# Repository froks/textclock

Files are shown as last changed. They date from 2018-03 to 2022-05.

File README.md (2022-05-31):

textclock
=========

# Introduction

textclock is a parametric 3d-printable textclock. It's currently in development.

It's designed to be used with a 60 led/m SK6812 led-strip, and an esp8266 using micropython for control. 
Using an ESP32 or any other micropython-capable board is also possible, but timer handling and pins might 
need to be changed.

The letterface is available in English and German, but can be easily adapted to other languages, as well as your
specific needs. The letters "stamped" into clock are just configuration files with text - look at the 
[english one](hardware/config_sk6812_english_minimal.scad) for a glimpse.

The configuration for most parameters is also adjustable in the [config_common.scad](hardware/config_common.scad) file. 

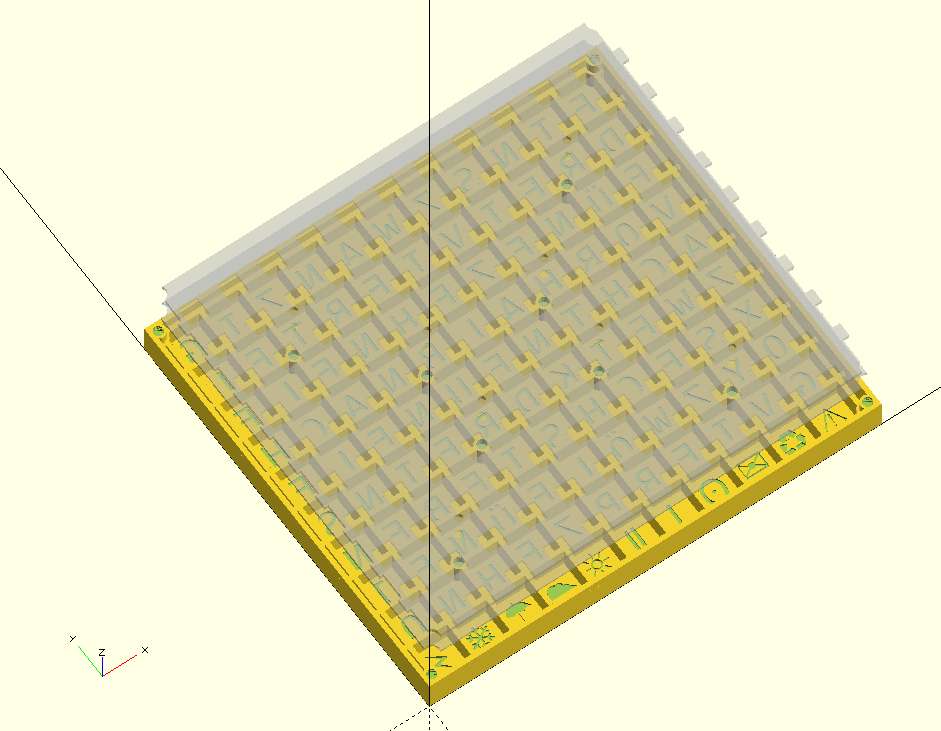
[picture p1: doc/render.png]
rendering


# Requirements

## Parts / BOM

In the default configuration the clock requires the following parts:

### 3d printed parts

__Note: Please read the Printed parts (IMPORTANT!)" section before you print them__

- letter plate (front face of the clock, includes the letters shown and separation between them)
- led holder plate (used with fixation plate to clamp the led strips between them)
- led fixation plate (used to clamp strips & serves as mount for electronics)
- backplate/wallmount (to close the case and enable mounting it to a wall)

### hardware
- M2.5 brass threaded inserts
- M2.5 machine screws (short, maybe 6mm?)

### electronics
- ESP8266 (or ESP32) NodeMCU-style board 
- SK6812 60 LEDs/m RGBW strip
- DS1307 RTC module (I used a dual module called "Tiny RTC" that additionally includes an eeprom, and just didn't it)
- THT angled pin headers (2.54mm)
- Jumper wires (F-F, just cut them up)
- misc. cables (you can use the jumper wire remains)

Since the 3d files are written in OpenSCAD, you can modify them to your needs and available electronics or led strips.  

## Printed parts (IMPORTANT!)

- 0.15mm layer height (some parameters in `config_common.scad` need to be changed if you want to use a different height)
- 0.4mm nozzle (for more detailed letters, you could potentially use a smaller nozzle)
- Filament: __Your filament choice is crucial for success.__ It must be opaque enough to block the light at ~1mm height, 
  but let light through at 0.15mm (single layer height). You can print a smaller test print
  to determine if your filament is suitable.   

# Assembly

## Printed parts

### Install threaded inserts

### Install led strips

## Electronics

### Prepare ESP8266

First step is to solder the angled pin headers to the ESP8266 board. Please note, that you may need to remove the 
standard headers first. 

## Software

The process of installing the software is described in the [software-folders README](software/README.md)

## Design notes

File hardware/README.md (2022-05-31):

### Recreate required stls

To recreate the required STL-files, you can run `build.bat`. Please note, that OpensCAD needs to be installed in `%PROGRAMFILES%\OpenSCAD\openscad.exe`.

If you want to manually recreate the files, you need to open, render & export the following files in OpenSCAD:
- led_fixation_plate.scad
- led_holder_plate.scad
- backplate_wall.scad
- letter_plate.scad

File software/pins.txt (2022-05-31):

ESP8266:

In most cases only pins 0, 2, 4, 5, 12, 13, 14, 15, and 16 can be used.

On my board:
Pin(0) = D3
Pin(2) = switches LED near antenna (low = led on)
Pin(4) = D2
Pin(5) = D1
Pin(12) = D6

sda = D2 = 4
scl = D1 = 5

import machine

i2c = machine.I2C(freq=100000,scl=machine.Pin(5), sda=machine.Pin(4))

import urtc

rtc = urtc.DS1307(i2c, 104)

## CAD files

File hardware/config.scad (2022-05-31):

include <config_common.scad>
include <config_sk6812_english_minimal.scad>
//include <config_sk6812_german.scad>
//include <config_tester.scad>
include <constants_calculated.scad>

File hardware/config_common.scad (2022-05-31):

$fn=20;

// Distance between two leds on a strip - depending on your mounting direction, only one is actually relevant,
// but to keep the clock square, they should be the
LED_STRIPE_HORIZ_DISTANCE = 16.66;
LED_STRIPE_VERT_DISTANCE = 16.66;

// The size of a single led module on that strip

// The stripe-segments are soldered together, at those points the distance between leds varies a lot,
// sometimes resoldering is required, so the distances between the leds match up
LED_STRIPE_LED_WIDTH = 8;
LED_STRIPE_LED_HEIGHT = 8;

// Since there are small capacitors right next to the leds, we need to provide a little space for them
LED_STRIPE_CAP_WIDTH = 3;
LED_STRIPE_CAP_HEIGHT = 5;
LED_STRIPE_CAP_DEPTH = 1.5; // 1;

// Defines the offset for those capacitors from the leds
LED_STRIPE_CAP_OFFSET_X = -4;
LED_STRIPE_CAP_OFFSET_Y = 0;

// Parameters for the screw holes
LETTER_PLATE_SCREW_INSERT_HEIGHT = 6; // 3.5;
LETTER_PLATE_SCREW_INSERT_WALL_THICKNESS = 2;
LETTER_PLATE_SCREW_INSERT_DIAMETER = 4; // M3 threaded insert diameter
LETTER_PLATE_SCREW_WALL_DIAMETER = LETTER_PLATE_SCREW_INSERT_DIAMETER + LETTER_PLATE_SCREW_INSERT_WALL_THICKNESS;
SCREW_DIAMETER = 3.2; // M3 screw diameter with tolerance

// Parameters for the corner holes (used to mount wallplate)
CORNER_MOUNTING_HOLE_INSERT_HEIGHT = LETTER_PLATE_SCREW_INSERT_HEIGHT;
CORNER_MOUNTING_HOLE_INSERT_DIAMETER = LETTER_PLATE_SCREW_INSERT_DIAMETER;
CORNER_MOUNTING_HOLE_INSERT_WALL_THICKNESS = LETTER_PLATE_SCREW_INSERT_WALL_THICKNESS;
CORNER_MOUNTING_HOLE_WALL_DIAMETER = CORNER_MOUNTING_HOLE_INSERT_DIAMETER + CORNER_MOUNTING_HOLE_INSERT_WALL_THICKNESS + 1;
CORNER_MOUNTING_HOLE_OFFSET = 1.85;

OUTER_HOLES_DIST = 2;
INNER_HOLES_DIST = 4;

LETTER_PLATE_LETTER_BOTTOM = 0.15;
LETTER_PLATE_THICKNESS = 1.05;
LETTER_SEPARATOR_THICKNESS = 2;
LETTER_SEPARATOR_HEIGHT = 10;

LED_HOLDER_PLATE_HEIGHT = 1.5;
INNER_PLATE_TOLERANCE = 1;

LED_HOLDER_PLATE_DIVIDER_CUTOUT_DEPTH = 0.6;
LED_HOLDER_PLATE_DIVIDER_CUTOUT_TOLERANCE = 1;

LED_FIXATION_CUTOUT_HEIGHT = 11;
LED_FIXATION_CUTOUT_WIDTH = 6;
LED_FIXATION_PLATE_THICKNESS = 2;

// Height of the backplate
WALLMOUNT_PLATE_THICKNESS = 6;

ELECTRONICS_HEIGHT = 15;

OUTER_WALL_THICKNESS = 2;
OUTER_WALL_HEIGHT = 2 + LETTER_SEPARATOR_HEIGHT +
    (LED_HOLDER_PLATE_HEIGHT-LED_HOLDER_PLATE_DIVIDER_CUTOUT_DEPTH) +
    LED_FIXATION_PLATE_THICKNESS + ELECTRONICS_HEIGHT;
// 2mm height tolerance to adjust fitting and led-stripe height

ROUND_EDGES_RADIUS = 3;

CONFIG_HORIZ_EXTRA = 0;
CONFIG_VERT_EXTRA = 0;


TESTER_MODE = false;

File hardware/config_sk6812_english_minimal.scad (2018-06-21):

// This work is licensed under a Creative Commons Attribution-NonCommercial-ShareAlike 4.0 International License.
// https://creativecommons.org/licenses/by-nc-sa/4.0/
// (c) 2018 Florian Roks <florian.roks (a) gmail.com>

FONT_NAMES = ["DejaVu Sans Mono", // 0
              "DejaVu Sans", // 1
              "Segoe UI Emoji",
			  "Segoe UI Symbol"];     // 2

FONT_SIZES = [10,
              10,
			  9,
			  10];


// FIVE TEN QUARTER TWENTY TWENTYFIVE HALF

// PAST TO 

// ONE TWO THREE FOUR FIVE SIX SEVEN EIGHT NINE TEN ELEVEN TWELVE

// O CLOCK


LETTERFACE = ["TWENTYFIVEN", 
              "QUARTERHALF",
              "TENEPASTNTO",
              "TWONETHREEQ",
			  "SIXFIVEFOUR",
			  "SEVENELEVEN",
			  "NINEIGHTENT",
			  "TWELVE\u263C\u2601\uE288\u2744\u26A1",
			  "\u2022\u2022O'CLOCK\u2022\u2022"];

LETTERFACE_FONTS = ["00000000000",
                    "00000000000",
                    "00000000000",
                    "00000000000",
                    "00000000000",
                    "00000000000",
                    "00000000000",
                    "00000013311",
                    "00000000000"];

CONFIG_HORIZ_EXTRA = 0;
CONFIG_VERT_EXTRA = 0;

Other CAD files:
hardware/config_sk6812_german.scad
hardware/backplate_wall.scad
hardware/common.scad
hardware/config_tester.scad
hardware/constants_calculated.scad
hardware/led_fixation_plate.scad
hardware/led_holder_plate.scad
hardware/letter_plate.scad
hardware/textclock.scad

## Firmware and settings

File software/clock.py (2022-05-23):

import time_funcs
import dst
import utime
import ntptime
import hw
import urtc
from config import LOCALE_SPECIFIC_PIXEL_UPDATE_FUNC


def sync_time_ntp():
    try:
        ntptime.settime()
        hw.rtc.datetime(datetime=utime.localtime(utime.time()))
        print("NTP - time synced")
    except Exception as e:
        print('Error while getting NTP-time: {}', e)


time_refresh_counter = 0


def refresh_time_display():
    global time_refresh_counter
    print('updating time-display')
    local_timestamp = dst.apply_dst_offset(urtc.tuple2seconds(hw.rtc.datetime()))
    time_tuple = utime.localtime(local_timestamp)
    print(time_tuple)
    # clear & fill pixel_buffer with next lit pixels
    # we need to buffer pixels, to ensure that we don't get weird in-between states while updating the time
    # since pixel_effect uses hw.lit_pixels constantly to display pixels
    for i in range(len(hw.pixel_buffer)):
        hw.pixel_buffer[i] = 0
    time_funcs.update_pixels_for_time(time_tuple[3], time_tuple[4], hw.pixel_buffer)
    if LOCALE_SPECIFIC_PIXEL_UPDATE_FUNC:
        LOCALE_SPECIFIC_PIXEL_UPDATE_FUNC(time_tuple[3], time_tuple[4], hw.pixel_buffer)

    # blit pixels to actually displayed pixels
    for i in range(len(hw.lit_pixels)):
        hw.lit_pixels[i] = hw.pixel_buffer[i]
    time_funcs.print_letterplate(hw.lit_pixels)

    if time_refresh_counter > 30:
        print_meminfo()
        time_refresh_counter = 0
    else:
        time_refresh_counter = time_refresh_counter + 1


def print_meminfo():
    import micropython
    import gc
    gc.collect()
    micropython.mem_info()

    if callable(getattr(gc, 'mem_free', None)):
        print('Initial free: {} allocated: {}'.format(gc.mem_free(), gc.mem_alloc()))


def start():
    sync_time_ntp()
    refresh_time_display()

    print("registering timers")
    hw.add_timer(10000, lambda x: refresh_time_display())  # update the displayed letters every 10 seconds
    hw.add_timer(600000, lambda x: sync_time_ntp())  # the rtc of esp8266 is *bad*, update from network every 10 minutes
    # hw.add_timer(30000, lambda x: print_meminfo())

    while True:
        hw.pixel_effect()


if __name__ == '__main__':
    start()

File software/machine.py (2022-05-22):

# simulate micropythons machine

import threading
import utime


def _bin2bcd(value):
    return (value or 0) + 6 * ((value or 0) // 10)


class Pin:
    OUT = 1

    def __init__(self, id, mode=-1, pull=-1):
        pass


class TimerTask:
    t = None
    callback = None
    period = None

    def __init__(self, period, callback):
        self.period = period
        self.callback = callback
        self.t = threading.Timer(interval=self.period/1000, function=self.obj_callback)
        self.t.start()

    def obj_callback(self):
        self.callback(self)
        self.t = threading.Timer(interval=self.period/1000, function=self.obj_callback)
        self.t.start()


class Timer:
    PERIODIC = 1

    tasks = []

    def __init__(self, id):
        pass

    def init(self, period, mode, callback):
        if mode != self.PERIODIC:
            raise Exception('unknown mode')
        self.tasks.append(TimerTask(period, callback))


class I2C:
    def __init__(self, freq, scl, sda):
        pass

    def readfrom_mem(self, address, register, len):
        buffer = bytearray(7)
        timestamp = utime.localtime(None)
        buffer[0] = _bin2bcd(timestamp[5])
        buffer[1] = _bin2bcd(timestamp[4])
        buffer[2] = _bin2bcd(timestamp[3])
        buffer[3] = _bin2bcd(timestamp[6])
        buffer[4] = _bin2bcd(timestamp[2])
        buffer[5] = _bin2bcd(timestamp[1])
        buffer[6] = _bin2bcd(timestamp[0] - 2000)
        return buffer

    def writeto_mem(self, address, register, buffer):
        pass

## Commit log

2018-03-24 adjusted tolerances
    [config.scad, led_fixation_plate.scad, led_holder_plate.scad]
2018-03-25 improve printability
    [config.scad, led_holder_plate.scad, letter_plate.scad]
2018-04-01 color wheeling + timers
2018-04-01 cleanup of some hardware files
    [backplate_wall.scad, common.scad, config.scad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]
2018-05-10 - work on english version - minor improvements - build.bat
    [backplate_wall.scad, common.scad, config.scad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]
2018-06-08 rtc (ds1307)
    [backplate_wall.scad, config_common.scad, constants_calculated.scad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]
2018-06-09 change some dimensions
    [config_common.scad, config_sk6812_english_minimal.scad, constants_calculated.scad]
2018-06-21 english version
    [backplate_wall.scad, config_common.scad, config_sk6812_english_minimal.scad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]
2022-05-23 hopefully fixes issue with "dot" symbols sometimes getting stuck
    [clock.py, hw.py, neopixel.py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]
2022-05-31 - changed 3d printed parts for nicer fit of backplate_wall - more documentation - license changed to MIT - added tester config
    [backplate_wall.scad, common.scad, config.scad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]
2022-05-31 make corner screwing mounts larger
    [config_common.scad, letter_plate.scad]
